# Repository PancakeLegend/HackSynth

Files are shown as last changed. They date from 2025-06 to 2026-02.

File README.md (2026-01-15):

# HackSynth
A MODULAR SYNTH PROJECT

### PROJECT ORIGIN STORY
- WE DISCOVERED A VERY AWESOME BREADBOARD SYNTH PROJECT CALLED BS-1, BY SOMEONE CALLED MAXWELL BECK. 
- WE DECIDED TO CREATE A MODULAR SYNTH BASED ON THIS PROJECT, BUT DESIGN PCBS RATHER THAN USING BREADBOARDS FOR EACH MODULE

### WHAT IS THE PURPOSE OF THIS PROJECT?

### WHAT'S THE VISION?
- A LOW COST WAY FOR ENTHUSIASTS TO BREAK INTO THE WORLD OF MODULAR SYNTHESIS

### WHO ARE WE
- WE ARE MEMBERS AT THE CONNECTED COMMUNITY HACKERSPACE - A COMMUNITY FOR

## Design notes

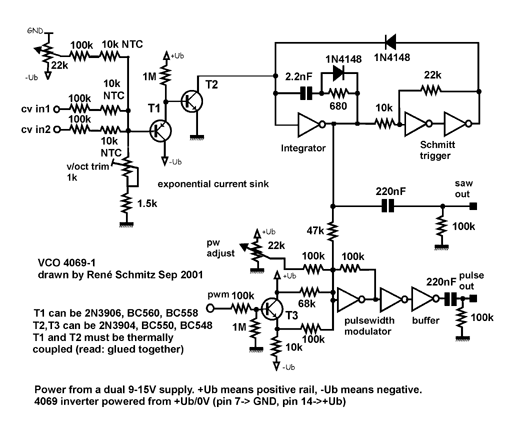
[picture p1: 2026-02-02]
KiCAD/VCO/v1-1/Reference/4069vco1.png

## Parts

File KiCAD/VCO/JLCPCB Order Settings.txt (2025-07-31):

Layers: 2
PCB Thickness: 1.6mm
PCB Color: Blue
Mark on PCB: Remove Mark

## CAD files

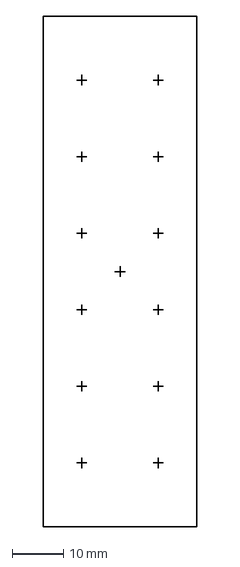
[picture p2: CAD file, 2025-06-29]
KiCAD/DXF/Grid 100x30.dxf
30.0 x 100.0 mm

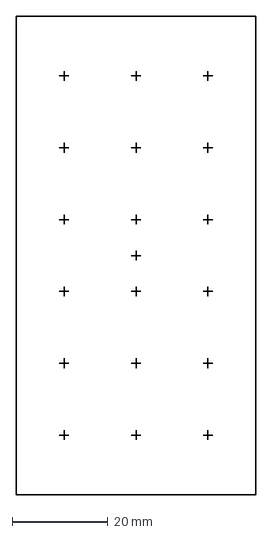
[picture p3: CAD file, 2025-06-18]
KiCAD/DXF/Grid 100x50 - 6x3.dxf
50.0 x 100.0 mm

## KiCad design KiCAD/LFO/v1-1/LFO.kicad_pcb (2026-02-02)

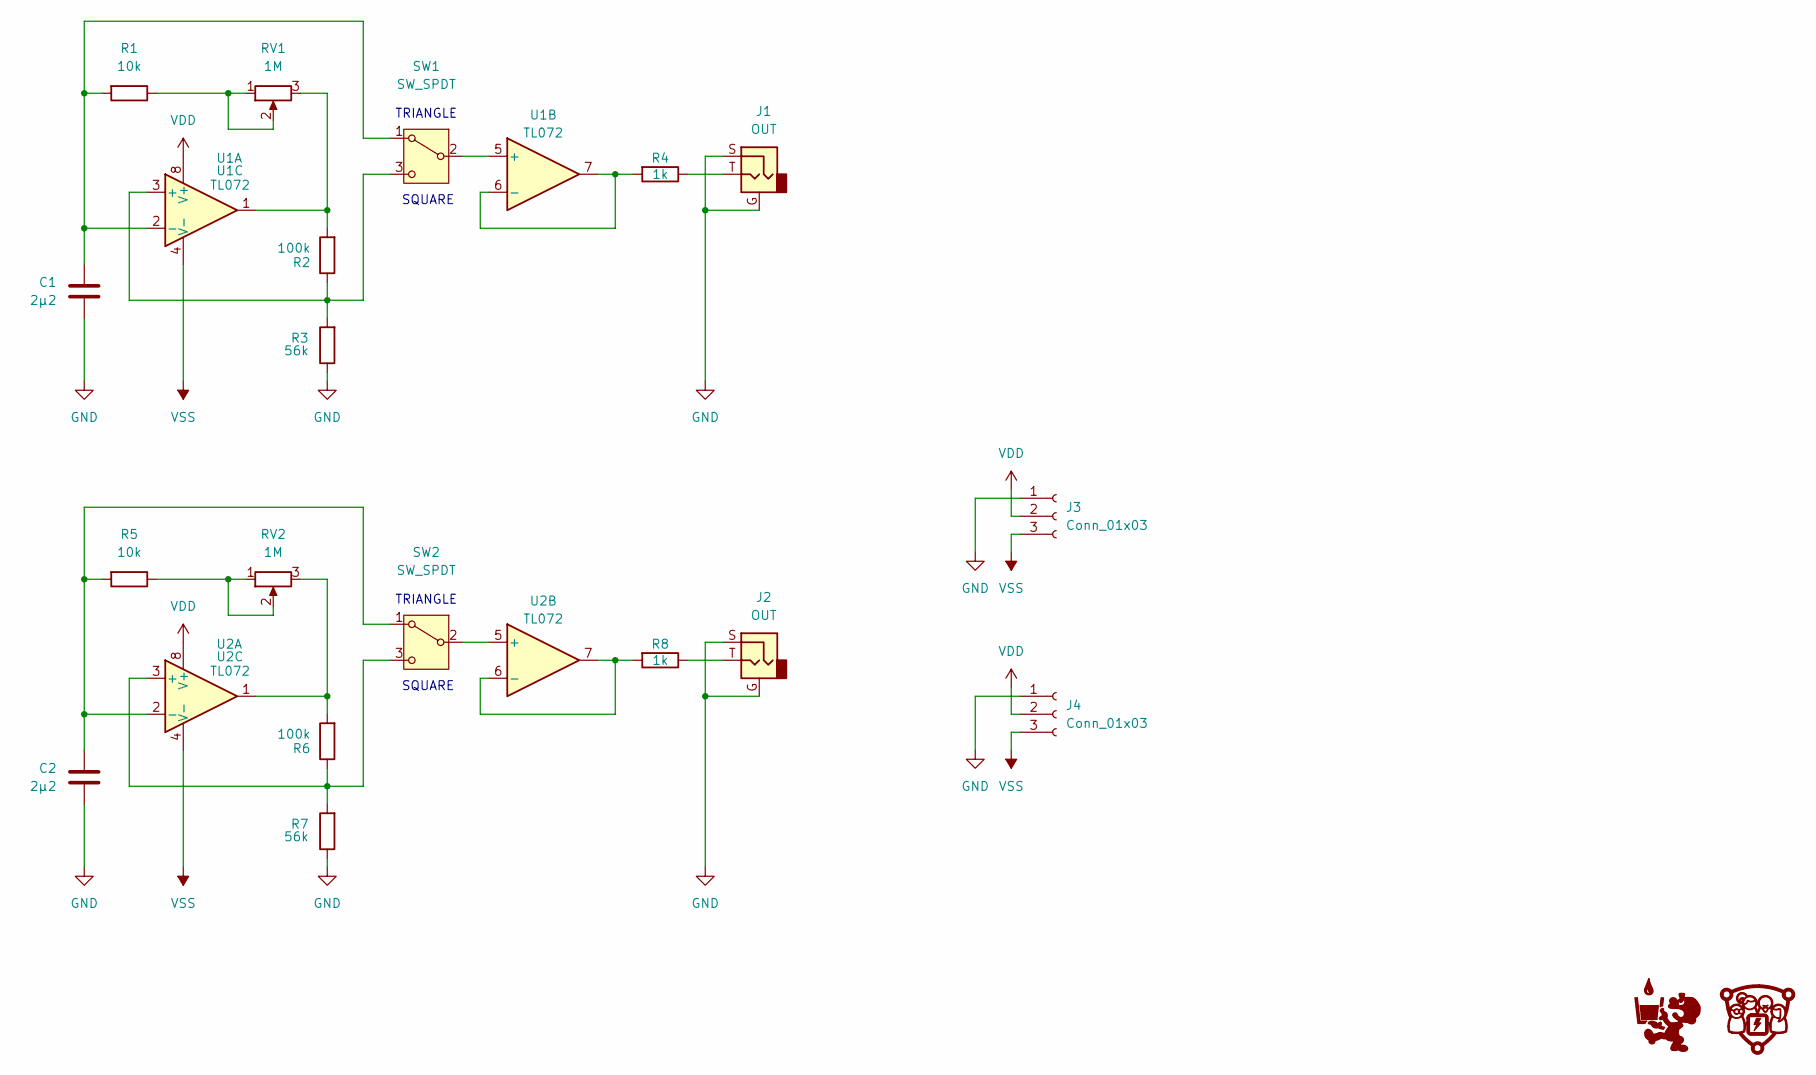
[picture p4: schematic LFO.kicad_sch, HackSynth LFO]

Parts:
C1, C2: 2µ2; C_Ceramic_D4.5mm_P5.00mm
G1, G2: (no value)
J1, J2: OUT; Jack_3.5mm
J3, J4: Conn_01x03; JST_PH_S3B-PH-K_1x03_P2.00mm_Horizontal
R1, R5: 10k; R_Axial_DIN0207_L6.3mm_D2.5mm_P7.62mm_Horizontal
R2, R6: 100k; R_Axial_DIN0207_L6.3mm_D2.5mm_P7.62mm_Horizontal
R3, R7: 56k; R_Axial_DIN0207_L6.3mm_D2.5mm_P7.62mm_Horizontal
R4, R8: 1k; R_Axial_DIN0207_L6.3mm_D2.5mm_P7.62mm_Horizontal
RV1, RV2: 1M; Potentiometer_Alps_RK09K_Horizontal
SW1, SW2: SW_SPDT; Switch SPDT - SMTS-102
U1, U2: TL072; DIP-8_W7.62mm_LongPads

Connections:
GND: C1.2, C2.2, J1.G, J1.S, J2.G, J2.S, J3.1, J4.1, R3.1, R7.1
unnamed: J1.T, R4.1
unnamed: J2.T, R8.1
unnamed: R1.1, RV1.1, RV1.2
unnamed: R2.2, RV1.3, U1.1
unnamed: R5.1, RV2.1, RV2.2
unnamed: R6.2, RV2.3, U2.1
unnamed: C1.1, R1.2, SW1.1 (A), U1.2 (-)
unnamed: SW1.2 (B), U1.5 (+)
unnamed: R2.1, R3.2, SW1.3 (C), U1.3 (+)
unnamed: C2.1, R5.2, SW2.1 (A), U2.2 (-)
unnamed: SW2.2 (B), U2.5 (+)
unnamed: R6.1, R7.2, SW2.3 (C), U2.3 (+)
unnamed: R4.2, U1.6 (-), U1.7
unnamed: R8.2, U2.6 (-), U2.7
VDD: J3.2, J4.2, U1.8 (V+), U2.8 (V+)
VSS: J3.3, J4.3, U1.4 (V-), U2.4 (V-)

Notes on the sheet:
SQUARE
TRIANGLE

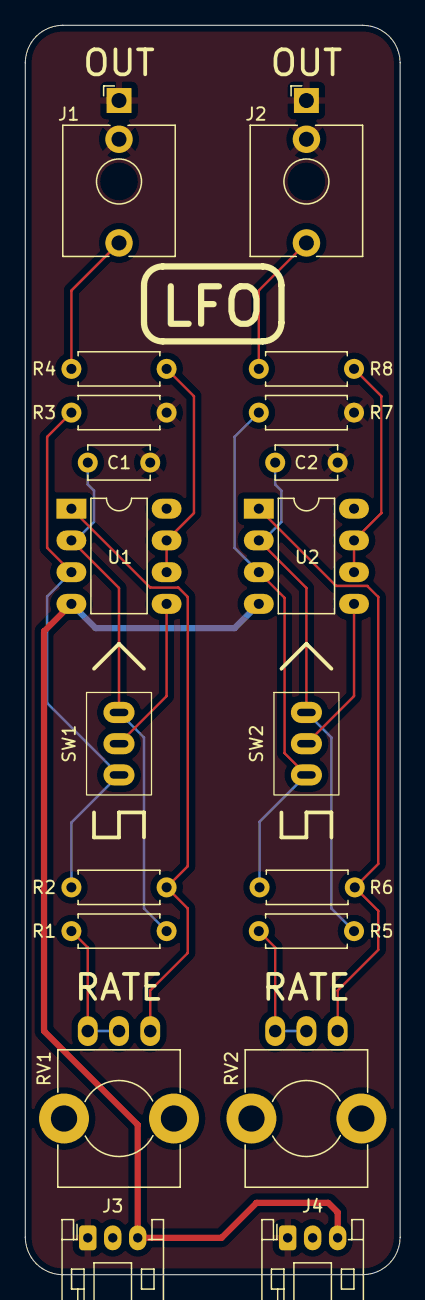
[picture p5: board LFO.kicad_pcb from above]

Board: 2 copper layers, 30.0 x 100.0 mm, 21 parts (1 on the bottom side), 17 nets.

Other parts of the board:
Ref**: Val**; CCHS Logo - 10mm

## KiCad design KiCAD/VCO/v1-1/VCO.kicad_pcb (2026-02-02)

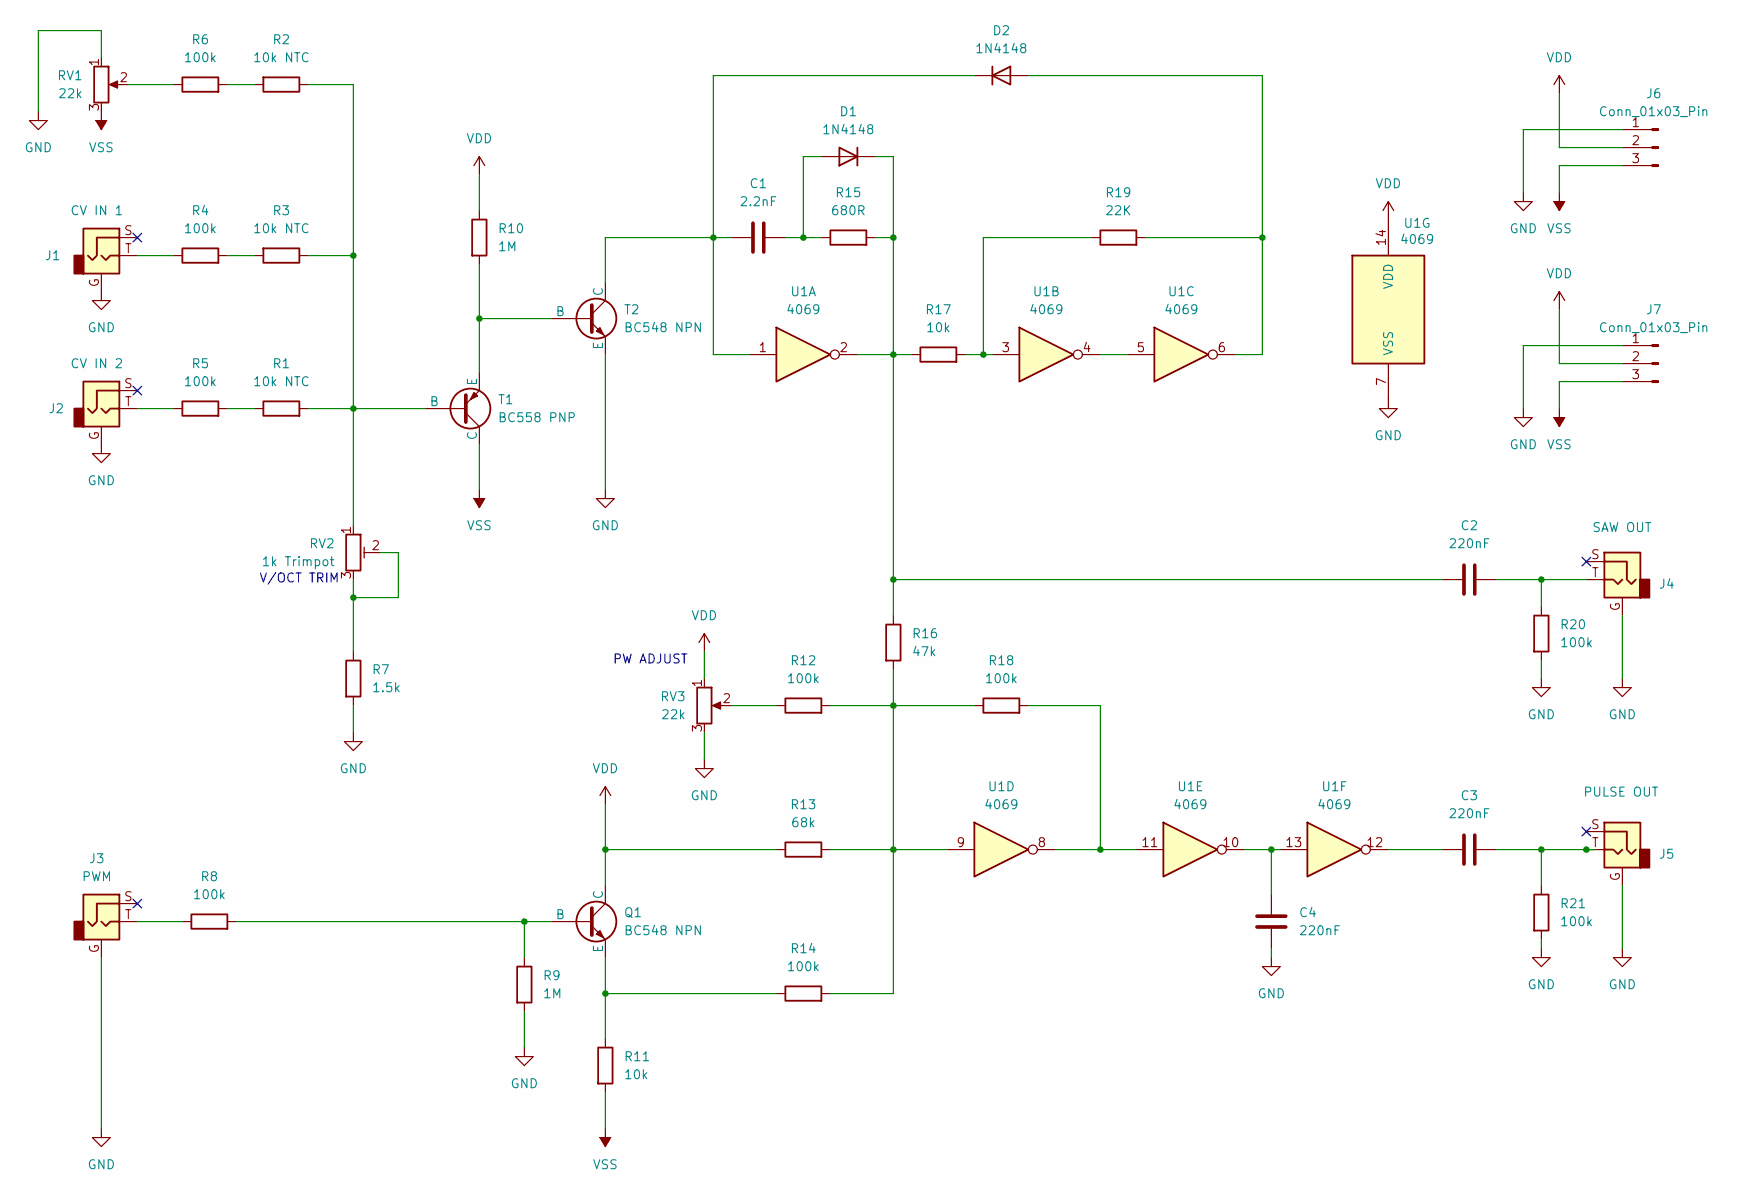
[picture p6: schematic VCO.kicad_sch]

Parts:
C1: 2.2nF; C_Disc_D5.0mm_W2.5mm_P2.50mm
C2, C3, C4: 220nF; C_Disc_D5.0mm_W2.5mm_P2.50mm
D1, D2: 1N4148; D_A-405_P7.62mm_Horizontal
J1: CV IN 1; Jack_3.5mm
J2: CV IN 2; Jack_3.5mm
J3: PWM; Jack_3.5mm
J4: SAW OUT; Jack_3.5mm
J5: PULSE OUT; Jack_3.5mm
J6, J7: Conn_01x03_Pin; JST_PH_S3B-PH-K_1x03_P2.00mm_Horizontal
Q1: BC548 NPN; TO-92_Inline - Handsolder
R1, R2, R3: 10k NTC; R_Axial_DIN0207_L6.3mm_D2.5mm_P2.54mm_Vertical
R4, R5, R6, R8, R12, R14, R18, R20, R21: 100k; R_Axial_DIN0207_L6.3mm_D2.5mm_P7.62mm_Horizontal
R7: 1.5k; R_Axial_DIN0207_L6.3mm_D2.5mm_P7.62mm_Horizontal
R9, R10: 1M; R_Axial_DIN0207_L6.3mm_D2.5mm_P7.62mm_Horizontal
R11, R17: 10k; R_Axial_DIN0207_L6.3mm_D2.5mm_P7.62mm_Horizontal
R13: 68k; R_Axial_DIN0207_L6.3mm_D2.5mm_P7.62mm_Horizontal
R15: 680R; R_Axial_DIN0207_L6.3mm_D2.5mm_P7.62mm_Horizontal
R16: 47k; R_Axial_DIN0207_L6.3mm_D2.5mm_P7.62mm_Horizontal
R19: 22K; R_Axial_DIN0207_L6.3mm_D2.5mm_P7.62mm_Horizontal
RV1, RV3: 22k; Potentiometer_Alps_RK09K_Horizontal
RV2: 1k Trimpot; TrimPot_Bourns_3339S_Horizontal
T1: BC558 PNP; TO-92_Inline - Handsolder
T2: BC548 NPN; TO-92_Inline - Handsolder
U1: 4069; DIP-14_W7.62mm_LongPads

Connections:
GND: C4.1, J1.G, J2.G, J3.G, J4.G, J5.G, J6.1, J7.1, R7.2, R9.2, R20.2, R21.2, RV1.1, RV3.3, T2.3 (E), U1.7 (VSS)
unnamed: C2.2, J4.T, R20.1
unnamed: C3.1, U1.12
unnamed: C3.2, J5.T, R21.1
unnamed: C4.2, U1.10, U1.13
unnamed: C1.2, D1.2 (A), R15.1
unnamed: C2.1, D1.1 (K), R15.2, R16.1, R17.1, U1.2
unnamed: D2.2 (A), R19.2, U1.6
unnamed: C1.1, D2.1 (K), T2.1 (C), U1.1
unnamed: J1.T, R4.1
unnamed: J2.T, R5.1
unnamed: J3.T, R8.1
unnamed: Q1.2 (B), R8.2, R9.1
unnamed: Q1.3 (E), R11.1, R14.1
unnamed: R1.1, R5.2
unnamed: R2.2, R6.2
unnamed: R3.2, R4.2
unnamed: R6.1, RV1.2
unnamed: R7.1, RV2.2, RV2.3
unnamed: R12.1, RV3.2
unnamed: R12.2, R13.2, R14.2, R16.2, R18.1, U1.9
unnamed: R17.2, R19.1, U1.3
unnamed: R18.2, U1.8, U1.11
unnamed: R1.2, R2.1, R3.1, RV2.1, T1.2 (B)
unnamed: R10.2, T1.3 (E), T2.2 (B)
unnamed: U1.4, U1.5
VDD: J6.2, J7.2, Q1.1 (C), R10.1, R13.1, RV3.1, U1.14 (VDD)
VSS: J6.3, J7.3, R11.2, RV1.3, T1.1 (C)

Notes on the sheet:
PW ADJUST
V/OCT TRIM

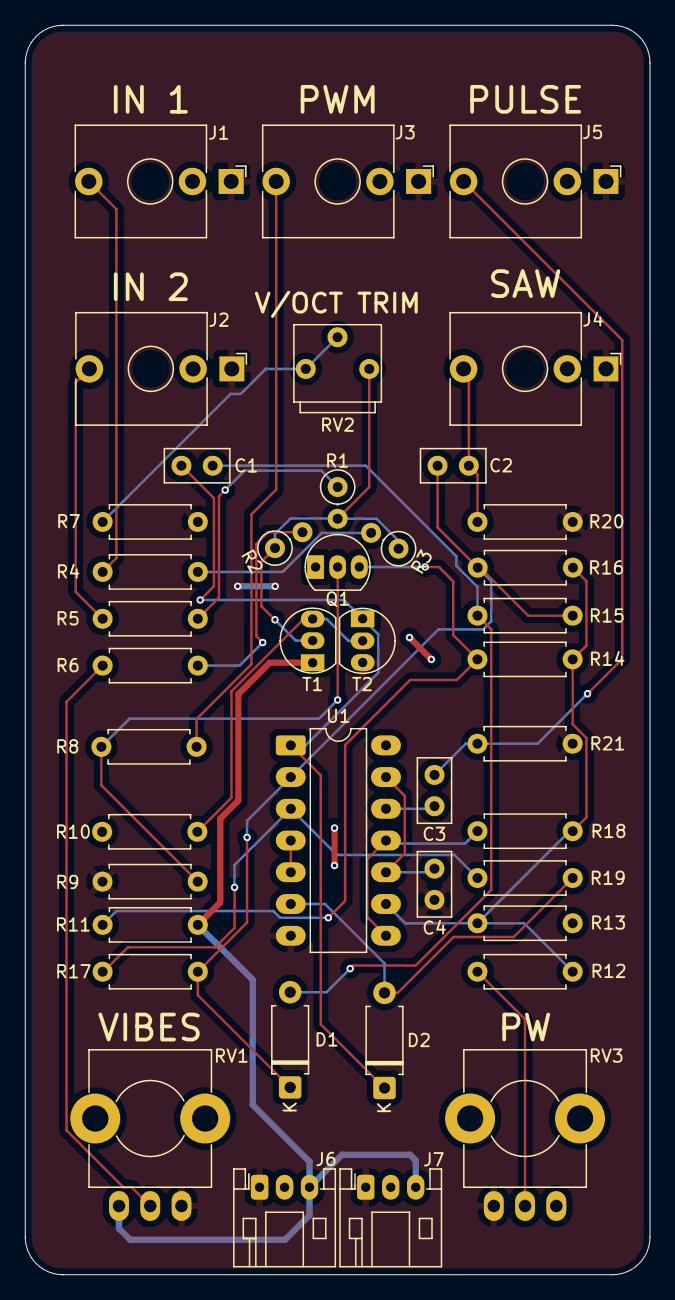
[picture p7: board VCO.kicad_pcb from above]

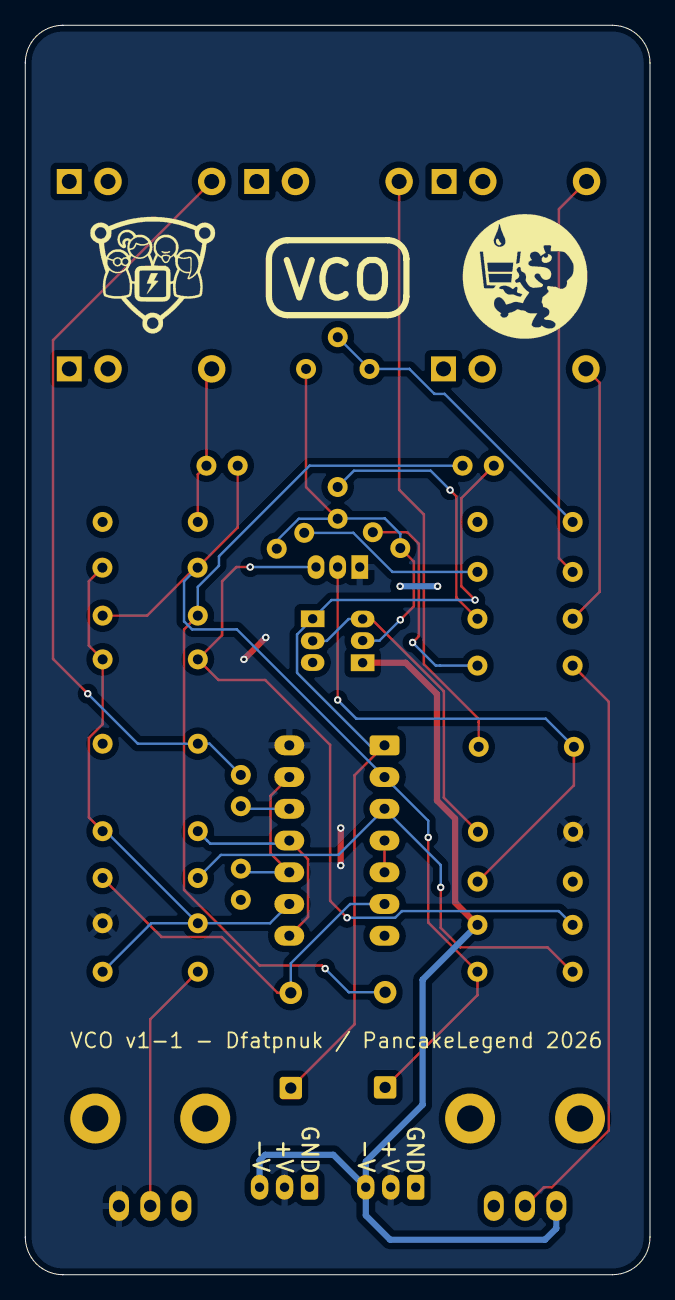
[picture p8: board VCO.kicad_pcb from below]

Board: 2 copper layers, 50.0 x 100.0 mm, 43 parts (2 on the bottom side), 28 nets.

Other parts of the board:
Ref**: Val**; CCHS Logo - 10mm
Ref**#2: Val**; PancakeLegend Logo - 10mm

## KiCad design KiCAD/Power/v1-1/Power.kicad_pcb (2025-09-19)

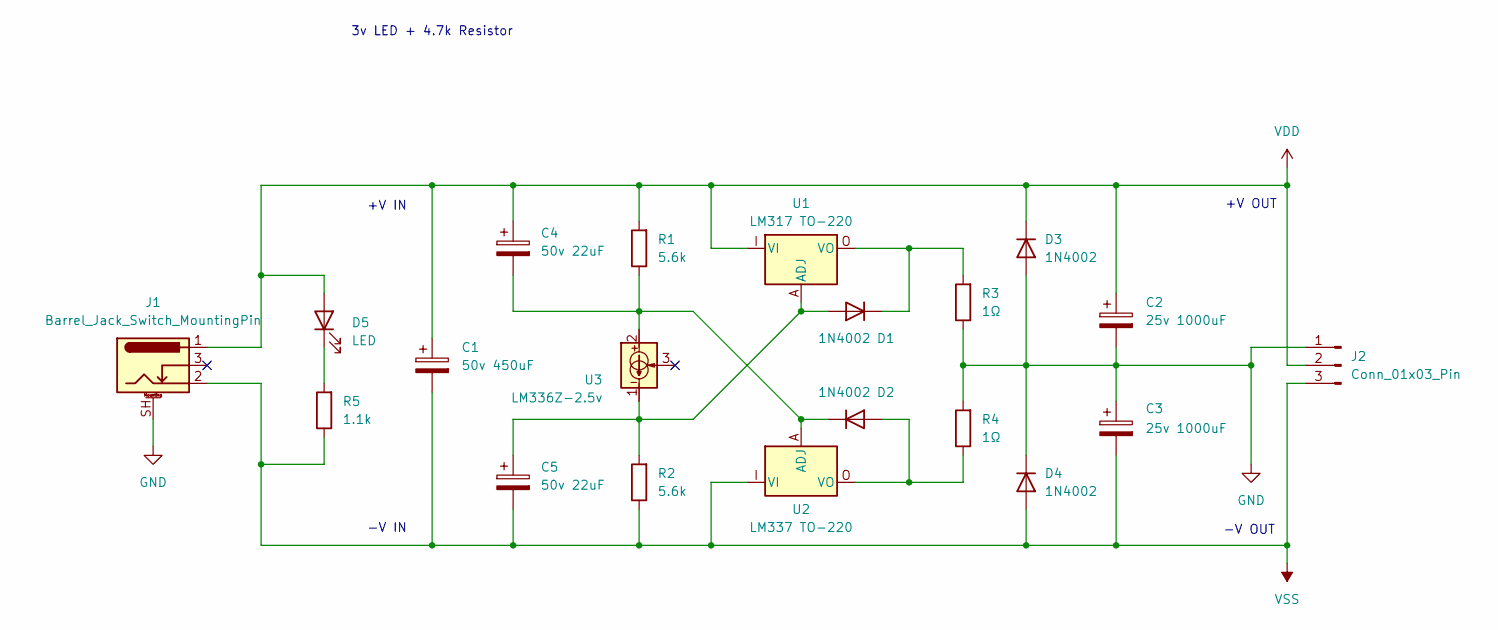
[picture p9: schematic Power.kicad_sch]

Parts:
C1: 50v 450uF; CP_Radial_D10.0mm_P5.00mm_MidMount
C2, C3: 25v 1000uF; CP_Radial_D10.0mm_P5.00mm_MidMount
C4, C5: 50v 22uF; CP_Radial_D5.2mm_P2.50mm_LayDown
D1, D2, D3, D4: 1N4002; D_A-405_P7.62mm_Horizontal
D5: LED; LED_D5.0mm
J1: Barrel_Jack_Switch_MountingPin; BarrelJack_DC044A
J2: Conn_01x03_Pin; JST_PH_S3B-PH-K_1x03_P2.00mm_Horizontal
R1, R2: 5.6k; R_Axial_DIN0207_L6.3mm_D2.5mm_P7.62mm_Horizontal
R3, R4: 1Ω; R_Axial_DIN0207_L6.3mm_D2.5mm_P7.62mm_Horizontal
R5: 1.1k; R_Axial_DIN0207_L6.3mm_D2.5mm_P7.62mm_Horizontal
U1: LM317 TO-220; LM317 - TO-220-3_Horizontal_TabDown
U2: LM337 TO-220; LM337 - TO-220-3_Horizontal_TabDown
U3: LM336Z-2.5v; TO-92_Inline - Handsolder

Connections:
GND: C2.2, C3.1, D3.2 (A), D4.1 (K), J1.SH (MountPin), J2.1, R3.1, R4.2
unnamed: C5.1, D1.2 (A), R2.2, U1.A (ADJ), U3.1
unnamed: D1.1 (K), R3.2, U1.O (VO)
unnamed: D2.2 (A), R4.1, U2.O (VO)
unnamed: C4.2, D2.1 (K), R1.1, U2.A (ADJ), U3.2
unnamed: D5.1 (K), R5.2
VDD: C1.1, C2.1, C4.1, D3.1 (K), D5.2 (A), J1.1, J2.2, R1.2, U1.I (VI)
VSS: C1.2, C3.2, C5.2, D4.2 (A), J1.2, J2.3, R2.1, R5.1, U2.I (VI)

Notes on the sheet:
3v LED + 4.7k Resistor
-V OUT
+V OUT
-V IN
+V IN

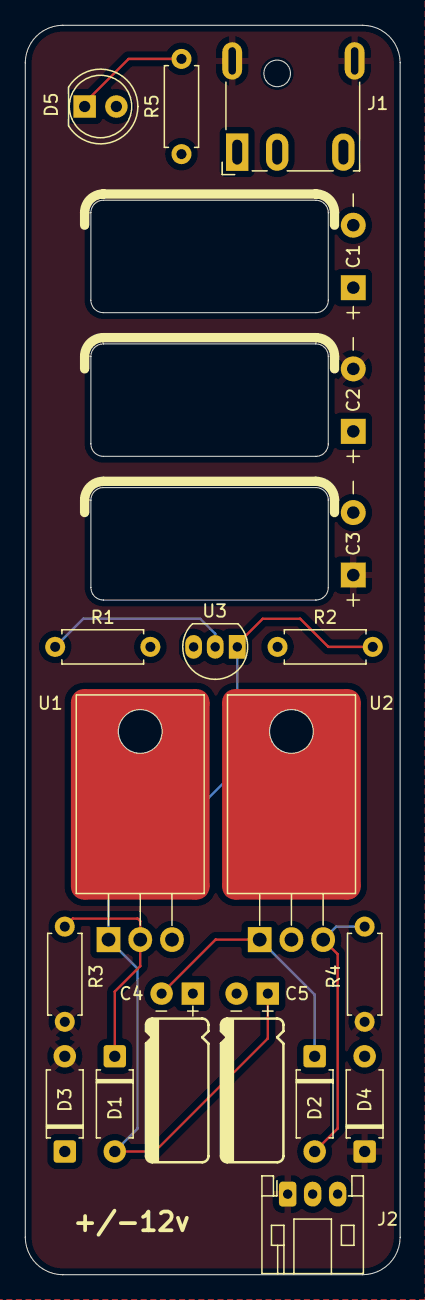
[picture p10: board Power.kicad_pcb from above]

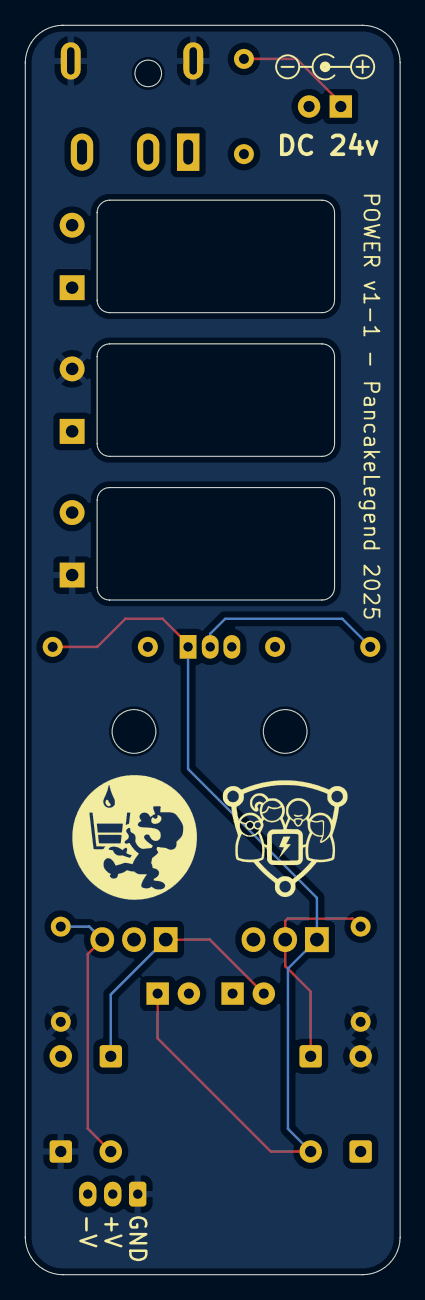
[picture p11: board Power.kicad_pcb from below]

Board: 4 copper layers, 30.0 x 100.0 mm, 22 parts (2 on the bottom side), 8 nets.

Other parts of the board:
Ref**: Val**; PancakeLegend Logo - 10mm
Ref**#2: Val**; CCHS Logo - 10mm

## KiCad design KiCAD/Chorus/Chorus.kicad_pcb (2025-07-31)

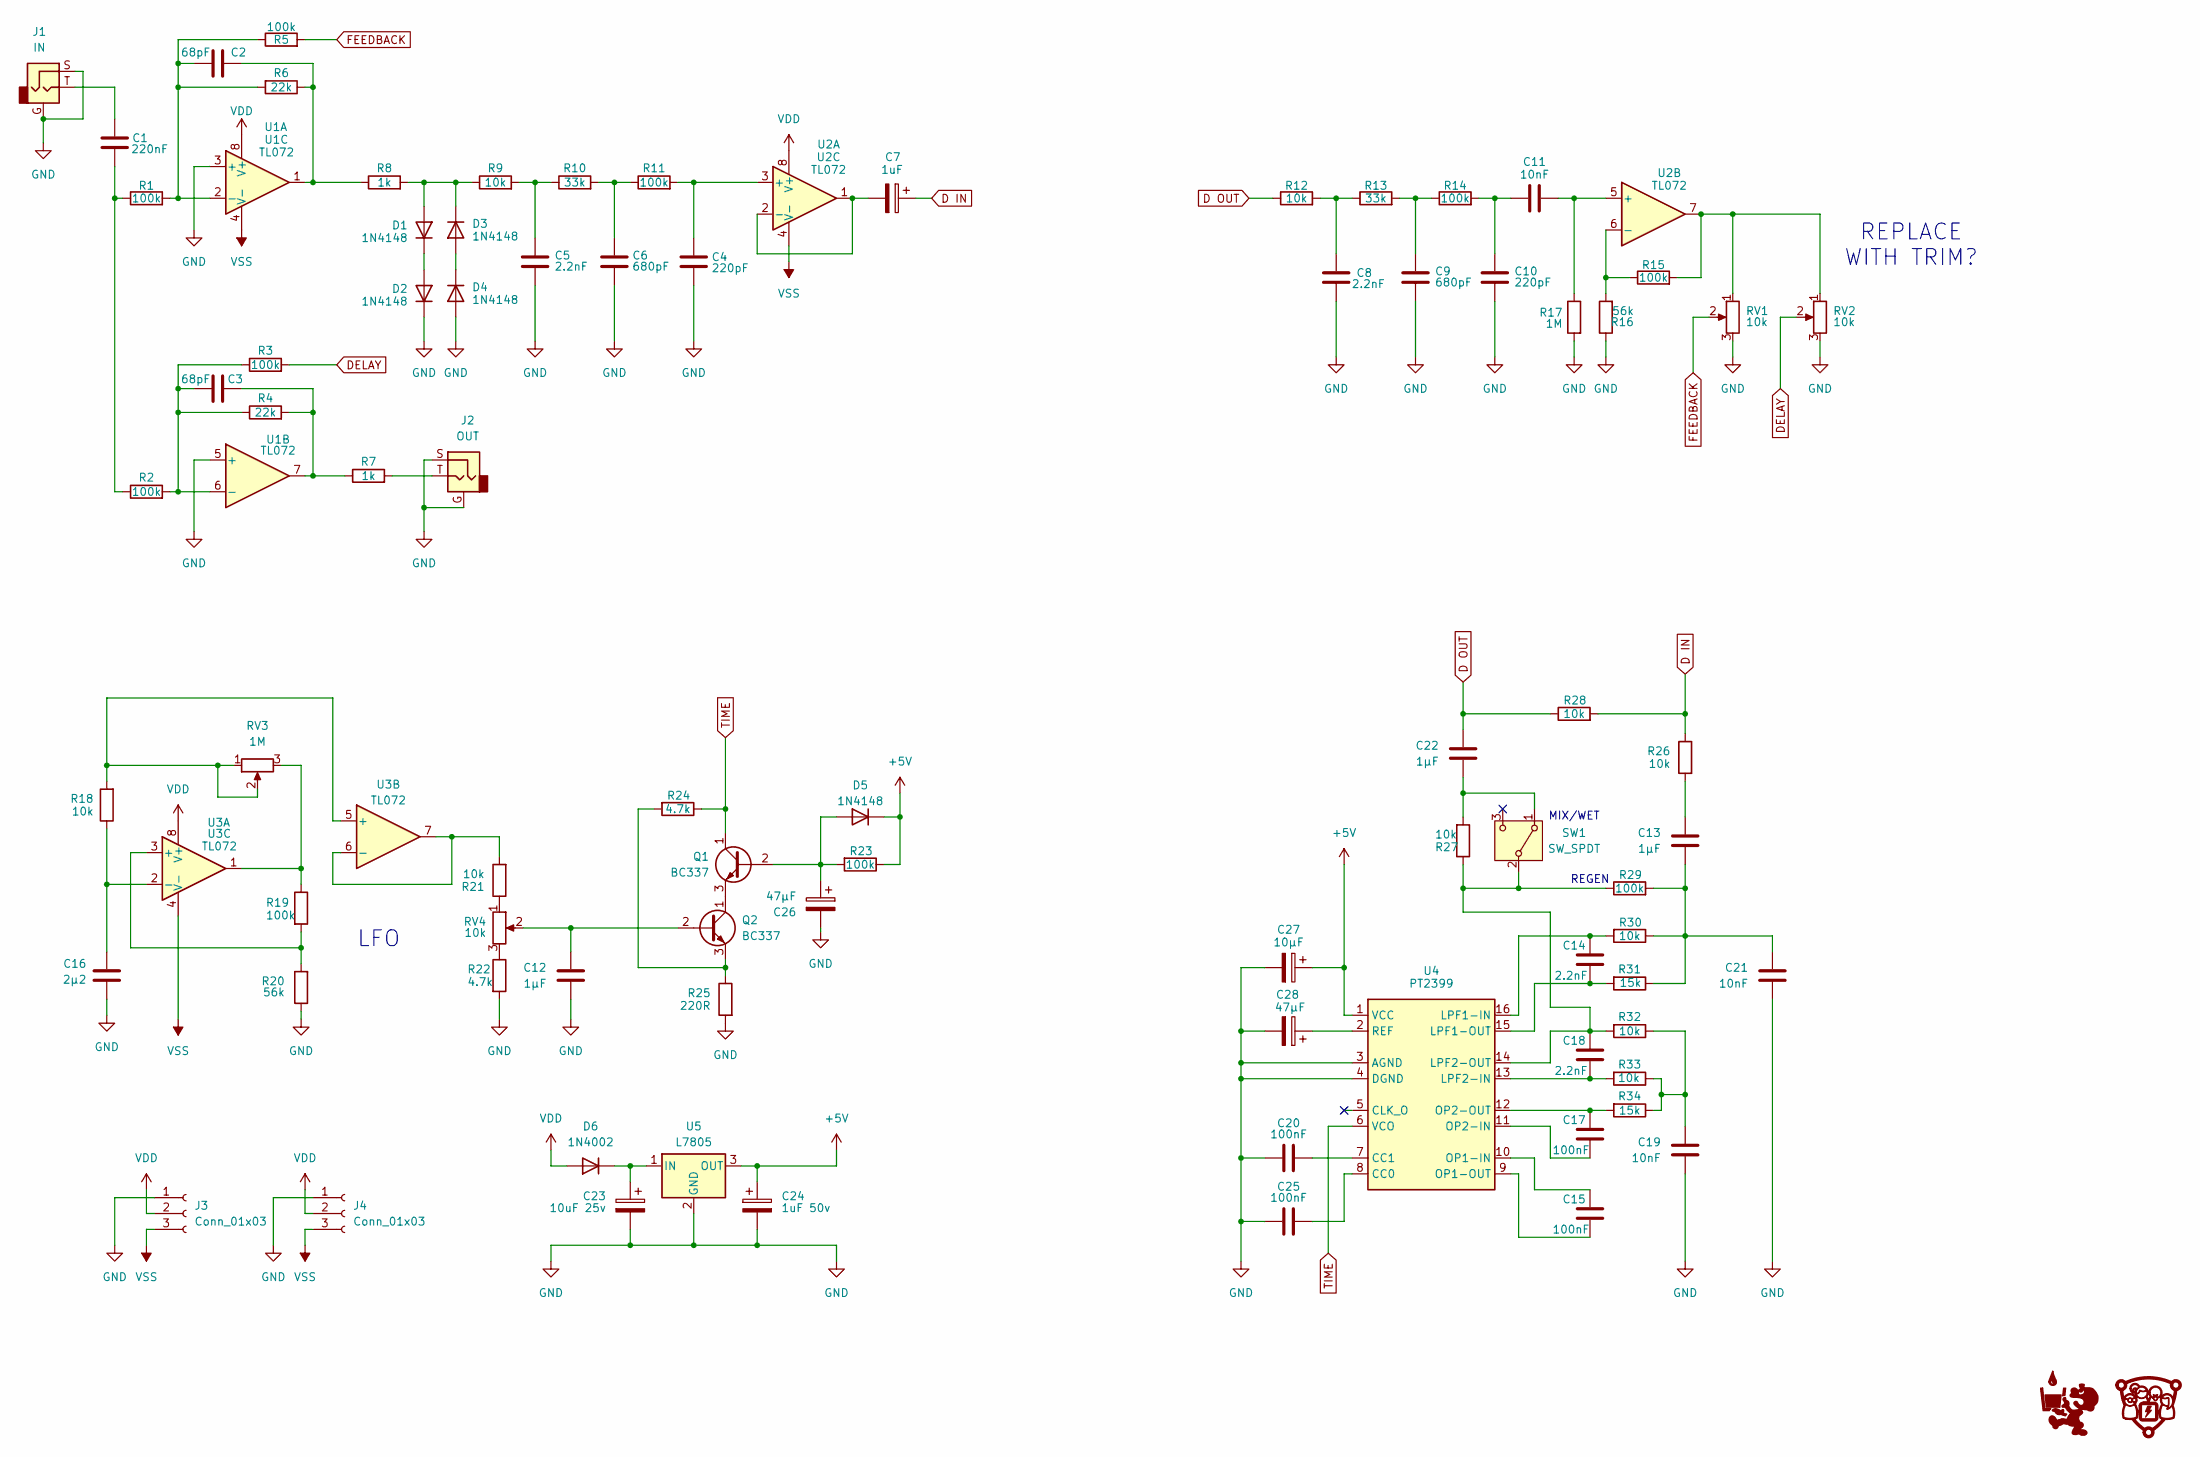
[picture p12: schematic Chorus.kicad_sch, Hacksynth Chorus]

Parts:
C1: 220nF; C_Ceramic_D4.5mm_P5.00mm
C2, C3: 68pF; C_Ceramic_D4.5mm_P5.00mm
C4, C10: 220pF; C_Ceramic_D4.5mm_P5.00mm
C5, C8, C14, C18: 2.2nF; C_Ceramic_D4.5mm_P5.00mm
C6, C9: 680pF; C_Ceramic_D4.5mm_P5.00mm
C7: 1uF; CP_Radial_D4.0mm_P1.50mm
C11, C19, C21: 10nF; C_Ceramic_D4.5mm_P5.00mm
C12, C13, C22: 1µF; C_Ceramic_D4.5mm_P5.00mm
C15, C17, C20, C25: 100nF; C_Ceramic_D4.5mm_P5.00mm
C16: 2µ2; C_Ceramic_D4.5mm_P5.00mm
C23: 10uF 25v; CP_Radial_D4.0mm_P1.50mm
C24: 1uF 50v; CP_Radial_D4.0mm_P1.50mm
C26, C28: 47µF; CP_Radial_D5.2mm_P2.50mm_LayDown
C27: 10µF; CP_Radial_D5.2mm_P2.50mm_LayDown_Mirror
D1, D2, D3, D4, D5: 1N4148; D_Vertical_P2.54mm
D6: 1N4002; D_A-405_P7.62mm_Horizontal
G1: Logo - CCHS 10mm
G2: Logo - PancakeLegend 10mm
J1: IN; Jack_3.5mm
J2: OUT; Jack_3.5mm
J3, J4: Conn_01x03; JST_PH_S3B-PH-K_1x03_P2.00mm_Horizontal
Q1, Q2: BC337; TO-92_Inline - Handsolder
R1, R2, R3, R5, R11, R14, R15, R19, R23, R29: 100k; R_Vertical_P2.54mm
R4, R6: 22k; R_Vertical_P2.54mm
R7, R8: 1k; R_Vertical_P2.54mm
R9, R12, R18, R21, R26, R27, R28, R30, R32, R33: 10k; R_Vertical_P2.54mm
R10, R13: 33k; R_Vertical_P2.54mm
R16, R20: 56k; R_Vertical_P2.54mm
R17: 1M; R_Vertical_P2.54mm
R22, R24: 4.7k; R_Vertical_P2.54mm
R25: 220R; R_Vertical_P2.54mm
R31, R34: 15k; R_Vertical_P2.54mm
RV1, RV2, RV4: 10k; Potentiometer_Alps_RK09K_Horizontal
RV3: 1M; Potentiometer_Alps_RK09K_Horizontal
SW1: SW_SPDT; Switch SPDT - SMTS-102
U1, U2, U3: TL072; DIP-8_W7.62mm_LongPads
U4: PT2399; DIP-16_W7.62mm_LongPads
U5: L7805; L7805 - TO-220-3_Horizontal_TabDown

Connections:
+5V: C24.1, C27.1, D5.1 (K), R23.1, U4.1 (VCC), U5.3 (OUT)
D IN: C7.1, R26.1, R28.2
D OUT: C22.1, R12.1, R28.1
DELAY: R3.2, RV2.2
FEEDBACK: R5.2, RV1.2
GND: C4.2, C5.2, C6.2, C8.1, C9.2, C10.2, C12.2, C16.2, C19.2, C20.2, C21.2, C23.2, C24.2, C25.2, C26.2, C27.2, C28.2, D2.1 (K), D4.2 (A), J1.G, J1.S, J2.G, J2.S, J3.1, J4.1, R16.1, R17.2, R20.1, R22.2, R25.2, RV1.3, RV2.3, U1.3 (+), U1.5 (+), U4.3 (AGND), U4.4 (DGND), U5.2 (GND)
unnamed: C1.1, R1.1, R2.1
unnamed: C1.2, J1.T
unnamed: C2.1, R6.1, R8.1, U1.1
unnamed: C3.2, R4.2, R7.1, U1.7
unnamed: C5.1, R9.2, R10.1
unnamed: C6.1, R10.2, R11.1
unnamed: C8.2, R12.2, R13.1
unnamed: C9.1, R13.2, R14.1
unnamed: C10.1, C11.1, R14.2
unnamed: C13.1, R26.2
unnamed: C13.2, C21.1, R29.2, R30.1, R31.1
unnamed: C19.1, R32.1, R33.1, R34.1
unnamed: D1.2 (A), D3.1 (K), R8.2, R9.1
unnamed: D1.1 (K), D2.2 (A)
unnamed: D3.2 (A), D4.1 (K)
unnamed: C26.1, D5.2 (A), Q1.2 (B), R23.2
unnamed: C23.1, D6.1 (K), U5.1 (IN)
unnamed: J2.T, R7.2
unnamed: Q1.3 (E), Q2.1 (C)
unnamed: C12.1, Q2.2 (B), RV4.2
unnamed: Q2.3 (E), R24.2, R25.1
unnamed: R15.2, RV1.1, RV2.1, U2.7
unnamed: R19.1, RV3.3, U3.1
unnamed: R21.1, RV4.1
unnamed: R22.1, RV4.3
unnamed: C22.2, R27.2, SW1.1 (A)
unnamed: C18.1, R27.1, R29.1, R32.2, SW1.2 (B), U4.14 (LPF2-OUT)
unnamed: C2.2, R1.2, R5.1, R6.2, U1.2 (-)
unnamed: C3.1, R2.2, R3.1, R4.1, U1.6 (-)
unnamed: C4.1, R11.2, U2.3 (+)
unnamed: C7.2, U2.1, U2.2 (-)
unnamed: C11.2, R17.1, U2.5 (+)
unnamed: R15.1, R16.2, U2.6 (-)
unnamed: R19.2, R20.2, U3.3 (+)
unnamed: C16.1, R18.1, U3.2 (-)
unnamed: R18.2, RV3.1, RV3.2, U3.5 (+)
unnamed: R21.2, U3.6 (-), U3.7
unnamed: C25.1, U4.8 (CC0)
unnamed: C20.1, U4.7 (CC1)
unnamed: C14.1, R30.2, U4.16 (LPF1-IN)
unnamed: C14.2, R31.2, U4.15 (LPF1-OUT)
unnamed: C18.2, R33.2, U4.13 (LPF2-IN)
unnamed: C15.1, U4.10 (OP1-IN)
unnamed: C15.2, U4.9 (OP1-OUT)
unnamed: C17.2, U4.11 (OP2-IN)
unnamed: C17.1, R34.2, U4.12 (OP2-OUT)
unnamed: C28.1, U4.2 (REF)
TIME: Q1.1 (C), R24.1, U4.6 (VCO)
VDD: D6.2 (A), J3.2, J4.2, U1.8 (V+), U2.8 (V+), U3.8 (V+)
VSS: J3.3, J4.3, U1.4 (V-), U2.4 (V-), U3.4 (V-)

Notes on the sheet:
MIX/WET
LFO
REPLACE WITH TRIM?
REGEN

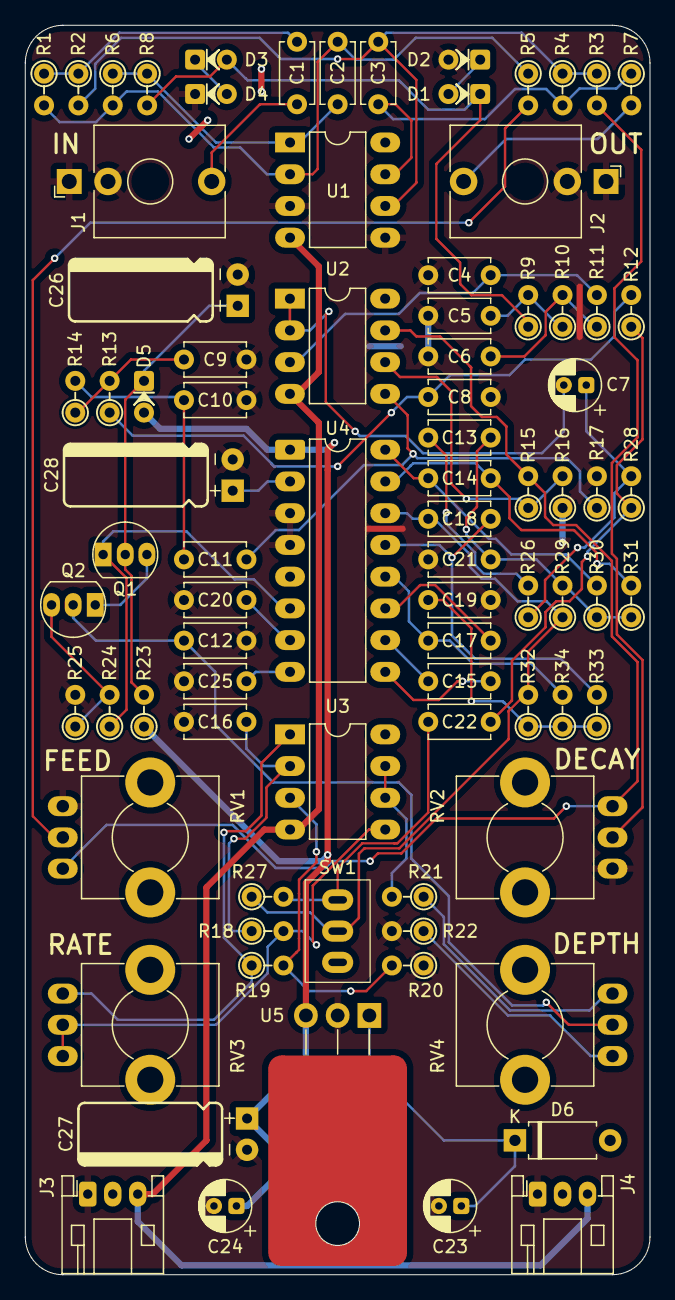
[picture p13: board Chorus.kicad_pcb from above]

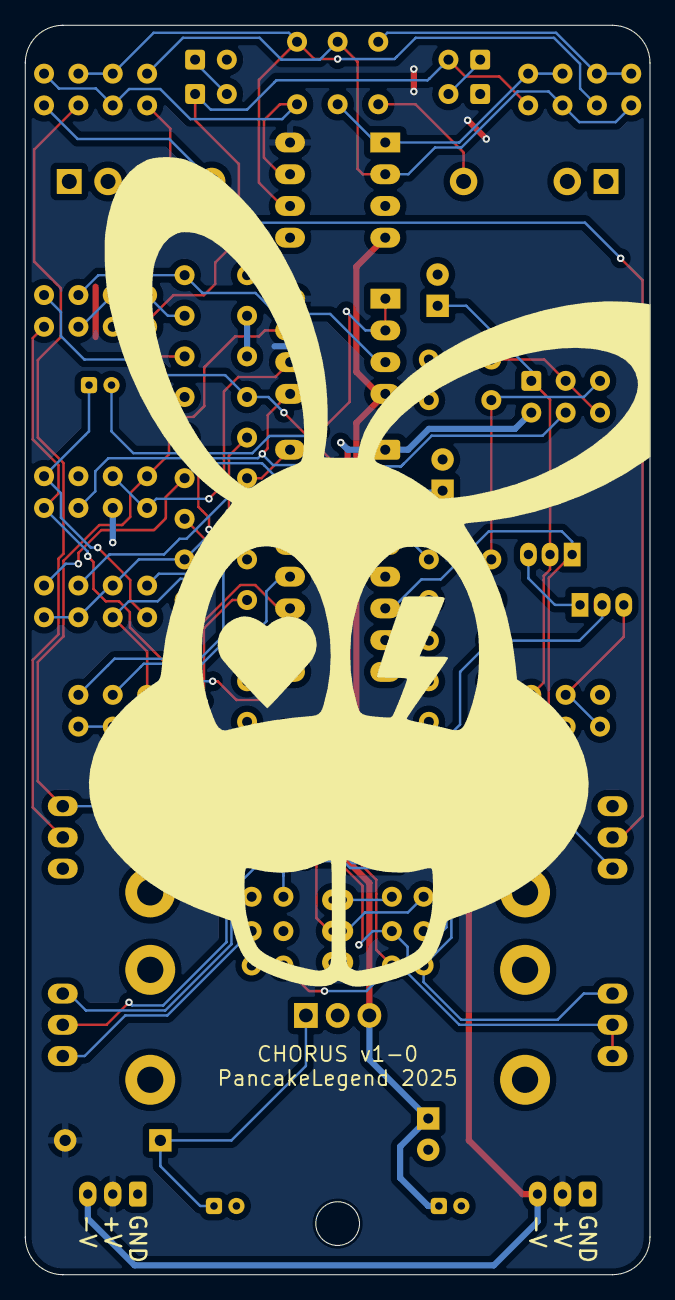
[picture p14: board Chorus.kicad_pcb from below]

Board: 2 copper layers, 50.0 x 100.0 mm, 86 parts (2 on the bottom side), 56 nets.

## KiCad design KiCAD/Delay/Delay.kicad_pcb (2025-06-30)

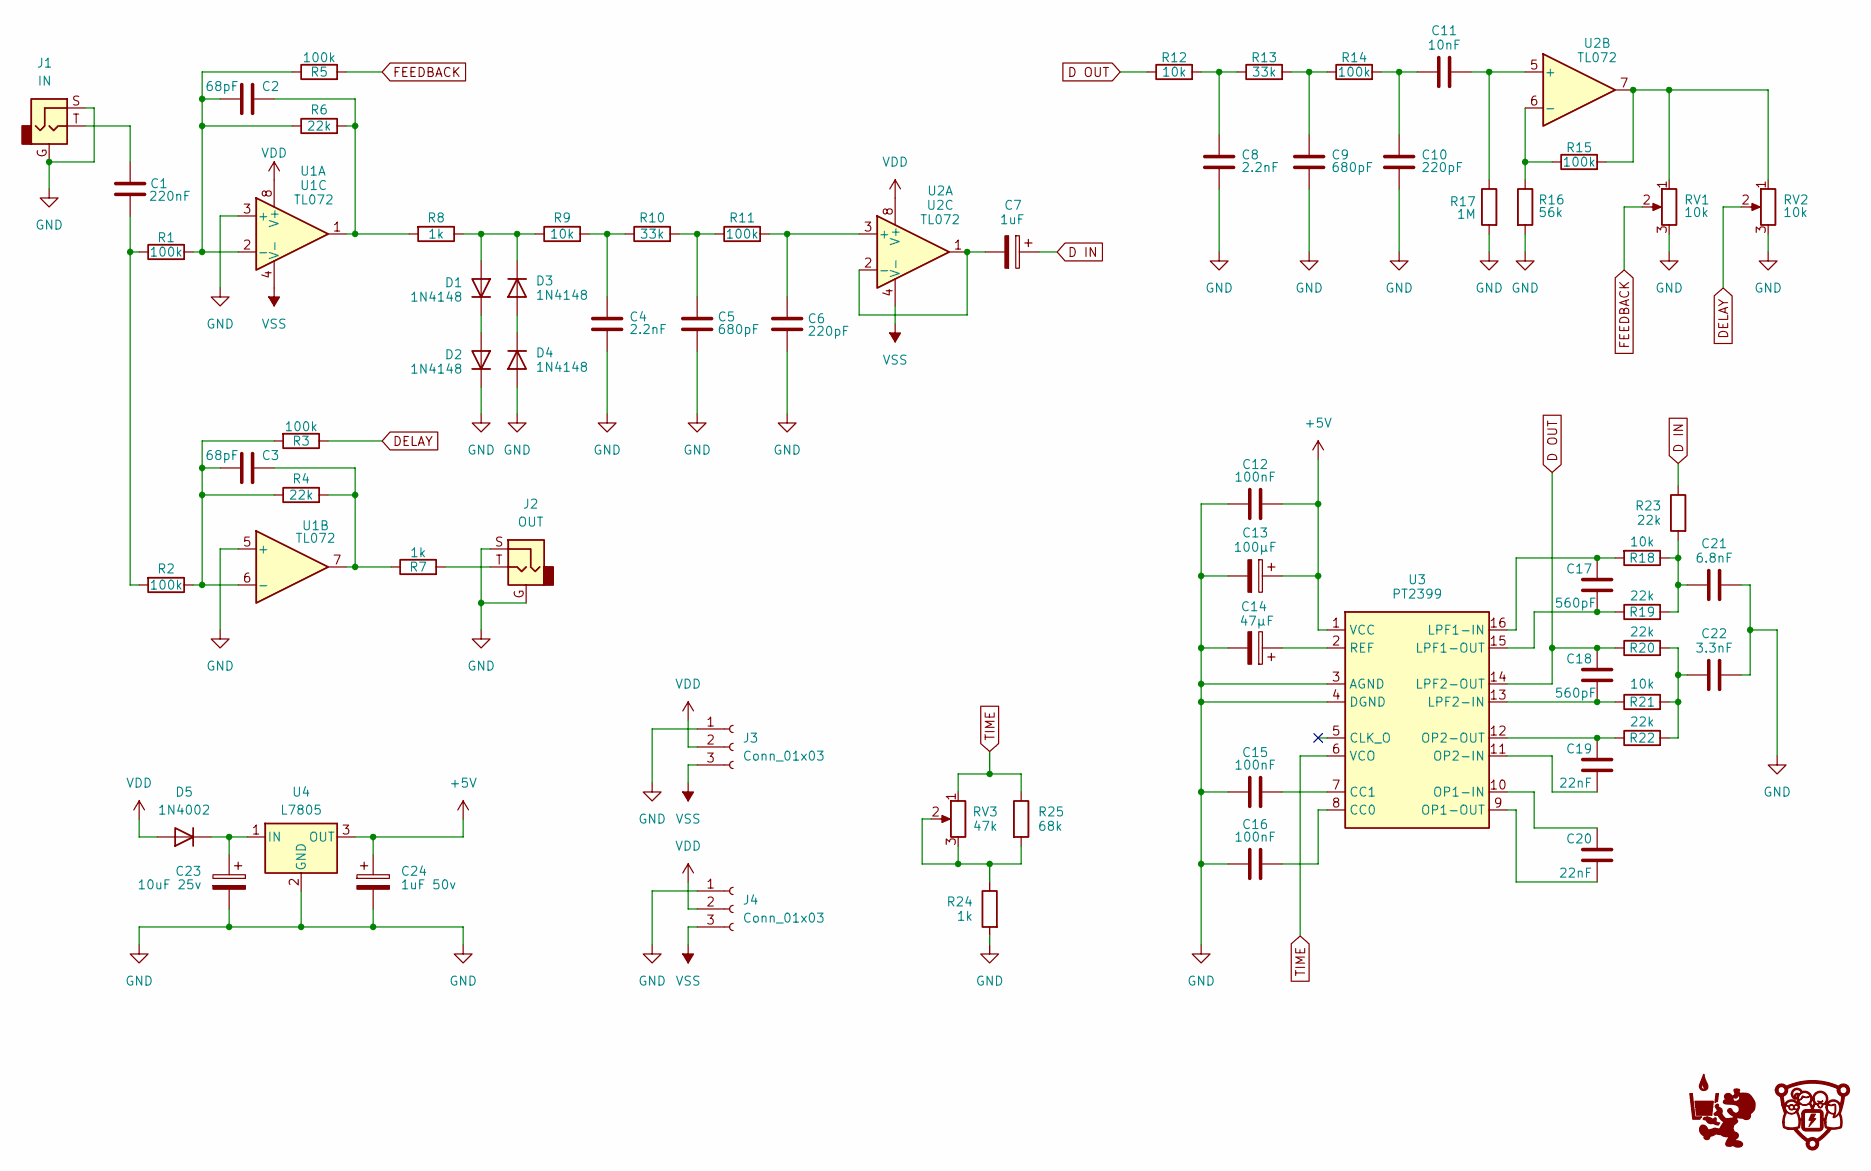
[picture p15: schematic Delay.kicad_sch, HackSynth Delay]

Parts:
C1: 220nF; C_Ceramic_D4.5mm_P5.00mm
C2, C3: 68pF; C_Ceramic_D4.5mm_P5.00mm
C4, C8: 2.2nF; C_Ceramic_D4.5mm_P5.00mm
C5, C9: 680pF; C_Ceramic_D4.5mm_P5.00mm
C6, C10: 220pF; C_Ceramic_D4.5mm_P5.00mm
C7: 1uF; CP_Radial_D4.0mm_P1.50mm
C11: 10nF; C_Ceramic_D4.5mm_P5.00mm
C12, C15, C16: 100nF; C_Ceramic_D4.5mm_P5.00mm
C13: 100µF; CP_Radial_D5.2mm_P2.50mm_LayDown_Mirror
C14: 47µF; CP_Radial_D5.2mm_P2.50mm_LayDown
C17, C18: 560pF; C_Ceramic_D4.5mm_P5.00mm
C19, C20: 22nF; C_Ceramic_D4.5mm_P5.00mm
C21: 6.8nF; C_Disc_D7.5mm_W5.0mm_P7.50mm
C22: 3.3nF; C_Disc_D7.5mm_W5.0mm_P7.50mm
C23: 10uF 25v; CP_Radial_D4.0mm_P1.50mm
C24: 1uF 50v; CP_Radial_D4.0mm_P1.50mm
D1, D2, D3, D4: 1N4148; D_Vertical_P2.54mm
D5: 1N4002; D_A-405_P7.62mm_Horizontal
G1, G2: (no value)
J1: IN; Jack_3.5mm
J2: OUT; Jack_3.5mm
J3, J4: Conn_01x03; JST_PH_S3B-PH-K_1x03_P2.00mm_Horizontal
R1, R2, R3, R5, R11, R14, R15: 100k; R_Vertical_P2.54mm
R4, R6, R19, R20, R22, R23: 22k; R_Vertical_P2.54mm
R7, R8, R24: 1k; R_Vertical_P2.54mm
R9, R12, R18, R21: 10k; R_Vertical_P2.54mm
R10, R13: 33k; R_Vertical_P2.54mm
R16: 56k; R_Vertical_P2.54mm
R17: 1M; R_Vertical_P2.54mm
R25: 68k; R_Vertical_P2.54mm
RV1, RV2: 10k; Potentiometer_Alps_RK09K_Horizontal
RV3: 47k; Potentiometer_Alps_RK09K_Horizontal
U1, U2: TL072; DIP-8_W7.62mm_LongPads
U3: PT2399; DIP-16_W7.62mm_LongPads
U4: L7805; L7805 - TO-220-3_Horizontal_TabDown

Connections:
+5V: C12.1, C13.1, C24.1, U3.1 (VCC), U4.3 (OUT)
D IN: C7.1, R23.1
D OUT: C18.1, R12.1, R20.1, U3.14 (LPF2-OUT)
DELAY: R3.1, RV2.2
FEEDBACK: R5.2, RV1.2
GND: C4.2, C5.2, C6.2, C8.2, C9.2, C10.2, C12.2, C13.2, C14.2, C15.2, C16.2, C21.1, C22.1, C23.2, C24.2, D2.1 (K), D4.2 (A), J1.G, J1.S, J2.G, J2.S, J3.1, J4.1, R16.2, R17.2, R24.2, RV1.3, RV2.3, U1.3 (+), U1.5 (+), U3.3 (AGND), U3.4 (DGND), U4.2 (GND)
unnamed: C1.1, R1.1, R2.2
unnamed: C1.2, J1.T
unnamed: C2.1, R6.2, R8.2, U1.1
unnamed: C3.1, R4.2, R7.1, U1.7
unnamed: C4.1, R9.2, R10.1
unnamed: C5.1, R10.2, R11.1
unnamed: C8.1, R12.2, R13.1
unnamed: C9.1, R13.2, R14.1
unnamed: C10.1, C11.1, R14.2
unnamed: C21.2, R18.1, R19.2, R23.2
unnamed: C22.2, R20.2, R21.2, R22.2
unnamed: D1.2 (A), D3.1 (K), R8.1, R9.1
unnamed: D1.1 (K), D2.2 (A)
unnamed: D3.2 (A), D4.1 (K)
unnamed: C23.1, D5.1 (K), U4.1 (IN)
unnamed: J2.T, R7.2
unnamed: R15.2, RV1.1, RV2.1, U2.7
unnamed: R24.1, R25.2, RV3.2, RV3.3
unnamed: C2.2, R1.2, R5.1, R6.1, U1.2 (-)
unnamed: C3.2, R2.1, R3.2, R4.1, U1.6 (-)
unnamed: C6.1, R11.2, U2.3 (+)
unnamed: C7.2, U2.1, U2.2 (-)
unnamed: C11.2, R17.1, U2.5 (+)
unnamed: R15.1, R16.1, U2.6 (-)
unnamed: C16.1, U3.8 (CC0)
unnamed: C15.1, U3.7 (CC1)
unnamed: C17.1, R18.2, U3.16 (LPF1-IN)
unnamed: C17.2, R19.1, U3.15 (LPF1-OUT)
unnamed: C18.2, R21.1, U3.13 (LPF2-IN)
unnamed: C20.1, U3.10 (OP1-IN)
unnamed: C20.2, U3.9 (OP1-OUT)
unnamed: C19.2, U3.11 (OP2-IN)
unnamed: C19.1, R22.1, U3.12 (OP2-OUT)
unnamed: C14.1, U3.2 (REF)
TIME: R25.1, RV3.1, U3.6 (VCO)
VDD: D5.2 (A), J3.2, J4.2, U1.8 (V+), U2.8 (V+)
VSS: J3.3, J4.3, U1.4 (V-), U2.4 (V-)

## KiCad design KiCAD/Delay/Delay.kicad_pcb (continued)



Board: 2 copper layers, 50.0 x 100.0 mm, 67 parts (2 on the bottom side), 43 nets.

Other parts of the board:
Ref**: Val**; Logo - PancakeLegend 10mm
Ref**#2: Val**; Logo - CCHS 10mm

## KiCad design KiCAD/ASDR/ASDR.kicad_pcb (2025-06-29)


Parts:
C1, C3: 220nF; C_Ceramic_D4.5mm_P5.00mm
C2: 10uF; CP_Radial_D4.0mm_P1.50mm
C4: 1uF; C_Ceramic_D4.5mm_P5.00mm
D1, D2, D3, D4: 1N4148; D_DO-35_SOD27_P7.62mm_Horizontal
D5: LED; LED_D5.0mm
G1, G2: (no value)
J1: IN; Jack_3.5mm
J2, J3: OUT; Jack_3.5mm
J4, J5: Conn_01x03; JST_PH_S3B-PH-K_1x03_P2.00mm_Horizontal
J6: Conn_02x05_Odd_Even
Q1, Q2, Q3: BC550; TO-92_Inline - Handsolder
Q4: BC547; TO-92_Inline - Handsolder
R1, R4: 10k; R_Axial_DIN0207_L6.3mm_D2.5mm_P7.62mm_Horizontal
R2: 100k; R_Axial_DIN0207_L6.3mm_D2.5mm_P7.62mm_Horizontal
R3, R5, R6: 4.7k; R_Axial_DIN0207_L6.3mm_D2.5mm_P7.62mm_Horizontal
R7, R8: 100R; R_Axial_DIN0207_L6.3mm_D2.5mm_P7.62mm_Horizontal
R9: 5.6k; R_Axial_DIN0207_L6.3mm_D2.5mm_P7.62mm_Horizontal
R10, R11, R12, R13: 1k; R_Axial_DIN0207_L6.3mm_D2.5mm_P7.62mm_Horizontal
RV1: SUSTAIN 10k; Potentiometer_Alps_RK09K_Horizontal
RV2: DECAY 1M; Potentiometer_Alps_RK09K_Horizontal
RV3: ATTACK 1M; Potentiometer_Alps_RK09K_Horizontal
RV4: RELEASE 1M; Potentiometer_Alps_RK09K_Horizontal
RV5: 100k Trim; TrimPot_Bourns_3339S_Horizontal
SW1: SW_SPDT; Switch SPDT - MTS-102
U1: ICM7555xP; DIP-8_W7.62mm_LongPads
U2, U3: TL072; DIP-8_W7.62mm_LongPads

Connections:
GND: C2.2, C3.2, C4.2, D1.2 (A), J1.G, J1.S, J2.G, J2.S, J3.G, J3.S, J4.1, J5.1, J6.3, J6.4, J6.5, J6.6, J6.7, J6.8, Q1.3 (E), Q2.3 (E), Q3.3 (E), R2.1, R11.1, RV5.3, U1.1 (GND)
unnamed: C1.1, D1.1 (K), Q3.2 (B)
unnamed: D2.2 (A), D3.1 (K), D4.2 (A), SW1.2 (B), U1.6 (THR), U2.5 (+)
unnamed: D2.1 (K), RV2.2, RV2.3
unnamed: D3.2 (A), RV3.1
unnamed: D4.1 (K), RV4.1
unnamed: D5.1 (K), Q4.1 (C)
unnamed: J1.T, R1.2
unnamed: J2.T, R12.1
unnamed: J3.T, R13.1
unnamed: Q1.2 (B), R1.1, R2.2
unnamed: Q1.1 (C), R3.1, R4.2
unnamed: Q2.2 (B), R4.1
unnamed: C1.2, Q2.1 (C), R5.1, R8.2, U1.4 (R)
unnamed: Q3.1 (C), R6.1, U1.2 (TR)
unnamed: Q4.2 (B), RV5.1, U2.6 (-), U2.7
unnamed: Q4.3 (E), R11.2
unnamed: R7.1, RV3.2, RV3.3
unnamed: R8.1, RV4.2, RV4.3
unnamed: R9.2, RV1.3
unnamed: R10.1, RV2.1
unnamed: C4.1, SW1.1 (A)
unnamed: C3.1, SW1.3 (C)
unnamed: C2.1, U1.5 (CV)
unnamed: RV1.1, U1.7 (DIS)
unnamed: R7.2, U1.3 (Q)
unnamed: RV1.2, U2.3 (+)
unnamed: R10.2, U2.1, U2.2 (-)
unnamed: RV5.2, U3.3 (+), U3.5 (+)
unnamed: R12.2, U3.1, U3.2 (-)
unnamed: R13.2, U3.6 (-), U3.7
VDD: D5.2 (A), J4.2, J5.2, J6.1, J6.2, R3.2, R5.2, R6.2, R9.1, U1.8 (VCC), U2.8 (V+), U3.8 (V+)
VSS: J4.3, J5.3, J6.9, J6.10, U2.4 (V-), U3.4 (V-)



Board: 2 copper layers, 50.0 x 100.0 mm, 42 parts (2 on the bottom side), 33 nets.

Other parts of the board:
Ref**: Val**; PancakeLegend Logo - 10mm
Ref**#2: Val**; CCHS Logo - 10mm

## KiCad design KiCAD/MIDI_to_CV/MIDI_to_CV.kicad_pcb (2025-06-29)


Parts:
C1: 100nF; C_Disc_D5.0mm_W2.5mm_P5.00mm
C2: 10uF 25v; CP_Radial_D4.0mm_P1.50mm
C3: 1uF 50v; CP_Radial_D4.0mm_P1.50mm
D1: 1N4148; D_DO-35_SOD27_P7.62mm_Horizontal
D2: 1N4002; D_A-405_P7.62mm_Horizontal
G1, G2: (no value)
J1: DIN-5_180degree; DIN-5 - DS-5-07A - MIDI Jack
J2: PITCH; Jack_3.5mm
J3: GATE; Jack_3.5mm
J4, J5: Conn_01x03_Socket; JST_PH_S3B-PH-K_1x03_P2.00mm_Horizontal
R1, R2: 220R; R_Axial_DIN0207_L6.3mm_D2.5mm_P7.62mm_Horizontal
R3: 4.7k; R_Axial_DIN0207_L6.3mm_D2.5mm_P7.62mm_Horizontal
R4, R5: 1k; R_Axial_DIN0207_L6.3mm_D2.5mm_P7.62mm_Horizontal
U1: ATtiny45-20P; DIP-8_W7.62mm_LongPads
U2: 6N138; DIP-8_W7.62mm_LongPads
U3: L7805; L7805 - TO-220-3_Horizontal_TabDown

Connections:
+5V: C3.1, R2.2, U1.8 (VCC), U2.8 (VCC), U3.3 (OUT)
GND: C1.2, C2.2, C3.2, J1.2, J2.G, J2.S, J3.G, J3.S, J4.1, J5.1, R3.1, U1.4 (GND), U2.5 (GND), U3.2 (GND)
unnamed: C1.1, J2.T, R4.2
unnamed: D1.2 (A), J1.5, U2.3 (C2)
unnamed: D1.1 (K), R1.2, U2.2 (C1)
unnamed: C2.1, D2.1 (K), U3.1 (IN)
unnamed: J1.4, R1.1
unnamed: J3.T, R5.2
unnamed: R4.1, U1.6 (PB1)
unnamed: R5.1, U1.7 (PB2)
unnamed: R3.2, U2.7 (VO1)
PB0: R2.1, U1.5 (AREF/PB0), U2.6 (VO2)
VDD: D2.2 (A), J4.2, J5.2
VSS: J4.3, J5.3



Board: 2 copper layers, 30.0 x 100.0 mm, 20 parts (2 on the bottom side), 14 nets.

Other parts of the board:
Ref**: Val**; CCHS Logo - 10mm
Ref**#2: Val**; PancakeLegend Logo - 10mm

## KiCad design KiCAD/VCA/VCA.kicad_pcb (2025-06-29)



Board: 2 copper layers, 30.0 x 100.0 mm, 17 parts (2 on the bottom side), 11 nets.

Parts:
C1: C; C_Disc_D5.0mm_W2.5mm_P5.00mm
J1: VIN; Jack_3.5mm
J2: VC; Jack_3.5mm
J3: VOUT; Jack_3.5mm
J4: Conn_01x03_Pin; JST_PH_S3B-PH-K_1x03_P2.00mm_Horizontal
Q1, Q2: J172; J172_TO-92_Inline - Handsolder
R1, R2, R3, R4: 10k; R_Axial_DIN0207_L6.3mm_D2.5mm_P7.62mm_Horizontal
R5: 27k; R_Axial_DIN0207_L6.3mm_D2.5mm_P7.62mm_Horizontal
RV1: 1kΩ TrimPot; TrimPot_Bourns_3339S_Horizontal
RV2: 100kΩ TrimPot; TrimPot_Bourns_3339S_Horizontal
Ref**: Val**; PancakeLegend Logo - 10mm
Ref**#2: Val**; CCHS Logo - 10mm
U1: LT1006; DIP-8_W7.62mm_LongPads

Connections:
GND: J1.G, J1.S, J2.G, J2.S, J3.G, J3.S, J4.1, Q1.3 (S), Q2.2 (G), Q2.3 (S), R4.2, RV2.3
unnamed: J1.T, R1.1, RV1.1
unnamed: J2.T, R5.1
unnamed: J3.T, R3.2, U1.6
unnamed: Q1.1 (D), R1.2, R3.1, U1.2 (-)
unnamed: Q1.2 (G), RV2.2
unnamed: Q2.1 (D), R2.2, R4.1, U1.3 (+)
unnamed: R2.1, RV1.2
unnamed: R5.2, RV2.1
VDD: C1.1, J4.2, U1.7 (V+)
VSS: C1.2, J4.3, U1.4 (V-)

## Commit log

2025-05-08 commenced VCO schematic.
    [VCO.kicad_sch]
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2025-05-15 Add footprint library components.
    [VCO.kicad_sch]
2025-05-16 VCO and Power updates
    [Power.kicad_sch, VCO.kicad_sch]
2025-05-18 Power Schematic and Libraries
    [Power.kicad_pcb, Power.kicad_sch, VCO.kicad_sch]
2025-05-18 MidMount Capacitors
    [Power.kicad_pcb, Power.kicad_sch]
2025-05-18 VCA Schematic
    [VCA.kicad_sch, VCO.kicad_pcb, VCO.kicad_sch]
2025-05-18 Power PCB
    [Power.kicad_pcb, Power.kicad_sch]
2025-05-20 VCA PCB Start
    [VCA.kicad_pcb, VCA.kicad_sch]
2025-05-21 Power PCB Gerbers
    [Power-B_Cu.gbr, Power-B_Mask.gbr, Power-B_Paste.gbr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]
2025-05-23 VCA PCB
    [Power.kicad_pcb, VCA.kicad_pcb, VCA.kicad_sch]
2025-05-23 3.5mm Jack
    [VCA.kicad_pcb]
2025-05-24 Power PCB Cleanup
    [Power.kicad_pcb]
2025-05-31 VCA Gerbers
    [VCA-B_Cu.gbr, VCA-B_Mask.gbr, VCA-B_Silkscreen.gbr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]
2025-05-31 Cap 3D Model Updates
    [Power.kicad_pcb]
2025-05-31 Footprint Update
    [Power.kicad_pcb]
2025-06-05 Mid VCO pcb session.
    [VCO.kicad_pcb, VCO.kicad_sch]
2025-06-07 VCO Board Setup
    Set up net classes and removed additional layers
    [VCO.kicad_pcb]
2025-06-08 Make VCA 2-Layer
    [VCA.kicad_pcb]
2025-06-08 MIDI to CV Schematic
    Heavy lifting done. Started on PCB Layout.
    [MIDI_to_CV.kicad_pcb, MIDI_to_CV.kicad_sch]
2025-06-08 MIDI to CV - PCB Placement
    [MIDI_to_CV.kicad_pcb, MIDI_to_CV.kicad_sch]
2025-06-08 MIDI to CV - PCB
    [MIDI_to_CV.kicad_pcb]
2025-06-09 MIDI Jack Footprint
    [MIDI_to_CV.kicad_pcb]
2025-06-09 MIDI to CV - Gerbers
    [MIDI_to_CV-B_Cu.gbr, MIDI_to_CV-B_Mask.gbr, MIDI_to_CV-B_Silkscreen.gbr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]
2025-06-09 VCA - Minor Trace Edit
    [VCA.kicad_pcb]
2025-06-10 Mixer Schematic
    [Mixer.kicad_sch]
2025-06-11 Mixer Footprint Association
    [Mixer.kicad_sch]
2025-06-13 Mixer PCB
    [Mixer-B_Cu.gbr, Mixer-B_Mask.gbr, Mixer-B_Silkscreen.gbr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]
2025-06-14 Mixer PCB - Gerbers
    [MIDI_to_CV.kicad_pcb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]
2025-06-14 LFO Schematic
    [LFO.kicad_sch]
2025-06-14 LFO PCB
    [LFO.kicad_pcb, LFO.kicad_sch, VCA.kicad_pcb]
2025-06-14 Library updates
    [LFO.kicad_pcb, LFO.kicad_sch]
2025-06-14 ASDR Schematic + LFO Gerbers
    [ASDR.kicad_sch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]
2025-06-14 ADSR PCB
    [ASDR-B_Cu.gbr, ASDR-B_Mask.gbr, ASDR-B_Silkscreen.gbr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]
2025-06-15 VCF Schematic
    [VCF.kicad_pcb, VCF.kicad_sch]
2025-06-15 VCF PCB Start
    [VCF.kicad_pcb]
2025-06-15 VCO PCB Resistor alignment.
    [VCO.kicad_pcb]
2025-06-15 VCO rearrange pcb
    [VCO.kicad_pcb]
2025-06-15 Vertical Resistor Footprint
    [VCF.kicad_sch]
2025-06-15 VCO pcb board population persists
    [VCO.kicad_pcb]
2025-06-16 ASDR PCB
    [ASDR - Tighter.kicad_pcb]
2025-06-16 Minor VCO update
    [VCO.kicad_pcb, VCO.kicad_sch]
2025-06-17 VCA Footprint update
    [VCA.kicad_pcb, VCA.kicad_sch]
2025-06-18 ADSR Rearrange
    [ASDR - Old.kicad_pcb, ASDR - Tighter.kicad_pcb, ASDR.kicad_pcb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]
2025-06-18 VCF PCB
    [ASDR-B_Cu.gbr, ASDR-B_Mask.gbr, ASDR-B_Silkscreen.gbr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]
2025-06-20 MIDI to CV Cap Footprint Change
    [MIDI_to_CV.kicad_pcb, MIDI_to_CV.kicad_sch, VCF.kicad_pcb]
2025-06-20 VCF Reorg
    [VCF-B_Cu.gbr, VCF-B_Mask.gbr, VCF-B_Silkscreen.gbr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]
2025-06-21 VCF Gerbers
    [VCF-B_Cu.gbr, VCF-B_Mask.gbr, VCF-B_Silkscreen.gbr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]
2025-06-22 Delay PCB
    [Delay.kicad_pcb, Delay.kicad_sch, LFO.kicad_sch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]
2025-06-23 Reapply VCO pcb layout changes.
    [VCO.kicad_pcb, VCO.kicad_sch]
2025-06-24 Backup Cleanup
    [Delay.kicad_pcb, Delay.kicad_sch, LFO.kicad_sch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]
2025-06-26 Make the transistors touch
    [VCO.kicad_pcb, VCO.kicad_sch]
2025-06-27 LFO v1-1
    [Delay.kicad_pcb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]
2025-06-27 Add a cap to pin 13
    [VCO.kicad_pcb, VCO.kicad_sch]
2025-06-29 Footprint Edits
    [ASDR.kicad_pcb, ASDR.kicad_sch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]
2025-06-30 Chorus Schematic
    [Chorus.kicad_pcb, Chorus.kicad_sch, Delay.kicad_pcb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]
2025-07-01 Rework VCO traces.
    [VCO.kicad_pcb]
2025-07-01 Bring jack back in line with grid
    [VCO.kicad_pcb]
2025-07-01 Chorus PCB Dread + Footprint Edit
    [Chorus.kicad_pcb, Chorus.kicad_sch, VCF.kicad_sch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]
2025-07-01 Clean up text references on VCO
    [VCO.kicad_pcb]
2025-07-03 remove unnecessary tracks
    [VCO.kicad_pcb]
2025-07-04 Chorus PCB Start
    [Chorus.kicad_pcb, Chorus.kicad_sch]
2025-07-05 Chorus Trace Begin
    [Chorus.kicad_pcb, Chorus.kicad_sch]
2025-07-05 Chorus Trace v1
    [Chorus.kicad_pcb, Chorus.kicad_sch]
2025-07-05 Chorus Legends
    [Chorus.kicad_pcb, Chorus.kicad_sch]
2025-07-06 Chorus DRC
    [Chorus.kicad_pcb]
2025-07-10 Rearrange text and add labels
    [VCO.kicad_pcb]
2025-07-10 Adjustments to labels
    [VCO.kicad_pcb]
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2025-07-26 Chorus Backups
    [Chorus.kicad_pcb]
2025-07-26 Fixing tracework
    [VCO.kicad_pcb]
2025-07-31 Chorus Gerbers
    [Chorus-B_Cu.gbr, Chorus-B_Mask.gbr, Chorus-B_Silkscreen.gbr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]
2025-07-31 Fix isolated VDD region
    [VCO.kicad_pcb]
2025-07-31 Create gerber files
    [VCO-B_Cu.gbr, VCO-B_Mask.gbr, VCO-B_Silkscreen.gbr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]
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2025-08-28 Fix missing resistor values
    [VCO.kicad_sch]
2025-09-19 Power v1-2
    [Power-B_Cu.gbr, Power-B_Mask.gbr, Power-B_Paste.gbr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]
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2026-02-02 Gerbers - Minor Edits
    [LFO-B_Cu.gbr, LFO-B_Mask.gbr, LFO-B_Silkscreen.gbr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]
